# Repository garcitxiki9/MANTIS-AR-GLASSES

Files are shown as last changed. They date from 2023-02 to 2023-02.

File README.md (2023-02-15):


# Mantis AR Glasses
An open source smart glasses



### Features

- Use a bluetooth multimeter and display the obtained data on the screen of the glasses.
- View the temperatures of electronic circuits with the MLX90640 thermal camera.

With these features, the Mantis AR Glasses wearer will be able to use a multimeter from the glasses and monitor circuit temperatures.

> ***This project has been realized by the students of the department of electronics of the institute CIFP Don Bosco LHII.***

- [ Mantis AR Glasses ](#mantis)
- [ Features ](#features)
- [ How did it start? ](#history)
	- [ Reverse engineering ](#reverse)
		- [ Vuzix Blade ](#vuzixblade)
		- [ Mantis Glasses ](#mantisglasses)
- [ What do we need? ](#whatweneed)
	- [ List of materials ](#listofmaterials)
	- [ Circuits and connections ](#circuits)
		- [ ST7735 Display ](#st7735)
		- [ MLX90640 ](#mlx90640)
		- [ Touch sensors ](#touchsensors)
		- [ Power management ](#power)
	- [ Software ](#software)
		- [ Install libraries ](#libraries)
		- [ Select the driver of our display ](#selectdriver)
		- [ Mirrored display ](#mirror)
- [ Bugs and error ](#bugserror)
- [ Thanks and references ](#thanks)
	- [ References ](#references)
- [ Disclaimer ](#disclaimer)

# How did it start?

We had the opportunity to test the Vuzix smart glasses and we thought it would be a good idea to do something similar but open source and cheaper.

One advantage of our glasses is that as they are open source, anyone with sufficient knowledge can improve them or adapt them to their needs.

## Reverse engineering
Before starting to design the parts, program or design the electronic circuits, we had to know how a smart glasses were made inside, so we disassembled the Vuxiz Blade to have a clearer idea of how to realize our project.

### Vuzix Blade

We had a better understanding of the required hardware after disassembling the smart glasses.

### Mantis Glasses




In this photo, you can see the components we used for our glasses based on the Vuzix Blade.

# What do we need?

## List of materials
Here is a detailed list of what we need to build our own smart glasses

- Microcontroller board (e.g. Arduino or ESP32)
- Display module (e.g. OLED or TFT)
- Micro-USB cable for programming and powering the board
- Lithium-ion battery or power bank
- 3D printer to print the frame
- Light reflective material to display the screen
- Power management circuit
- Wi-Fi or Bluetooth module
- Sensors (e.g. accelerometer, gyroscope, proximity)
- Buttons or touchpad for user input
- Wiring and cables to connect the components
- A software development kit and libraries to program the glasses.

In our case, we will use an ESP32 because it already has integrated WiFi and Bluetooth, and our sensor will be a thermal camera and a TFT RGB IPS screen because it offers higher resolution for using the thermal camera.

## Circuits and connections

### ST7735 Display


| ST7735 PIN | ESP32 PIN |
| :--- | :-----:|
| GND | GND |
| VCC | 3V3 | 
| SCL | 15 |
| SDA | 2 | 
| RES | 4 |
| DC | 16 | 
| CS | 17 |
| BLK | No connected |

### MLX90640


| MLX90640 PIN | ESP32 PIN |
| :--- | :-----:|
| GND | GND |
| VIN | 3V3 | 
| SCL | 22 |
| SDA | 21 | 
| PS | GND |

### Touch sensors



| TOUCH PIN | ESP32 PIN |
| :--- | :-----:|
| GND | GND |
| VIN | 3V3 | 
| LEFT | 26 |
| GO BACK | 14 | 
| SELECT | 27 |
| RIGHT | 25 |

### Power management


| BATTERY PIN | ESP32 PIN |
| :--- | :-----:|
| BATT- | GND |
| BAT+ | 3V3 | 
| VOLTAGE DIVIDER OUTPUT  | 34 |

## Software

### Install libraries
To install a library in arduino we have to go to :
- sketch->include library->manage libraries


And a window will open where we can look for the name of the library:
- TFT_eSPI



### Select the driver of our display
Once we have installed the TFT_eSPI library, we need to locate the library folder, which is located in the Arduino folder.
`C:\Users\Carlos\This PC\Documents\Arduino\libraries\TFT_eSPI`
Next, we need to edit the file named
`User_Setup_Select.h`
By default, it will contain the line
`#include <User_Setup.h>`
We need to comment out this line and locate the driver for our screen, in our case
`#include <User_Setups/Setup43_ST7735.h>`
and uncomment it.

It should look something like this:

```c++
...
//#include <User_Setup.h>           // Default setup is root library folder
...
#include <User_Setups/Setup43_ST7735.h>            // Setup file for ESP8266 & ESP32 configured for my ST7735S 80x160
...
```

### Mirrored display


```c++

tft.writecommand(TFT_MADCTL); //access to display memory
tft.writedata(0xE0); // send data to change to mirror effect
```

## Future improvements


- A good improvement of this project would be to implement AI, you can use the Whisper AI to talk and pass the audio to text to send it to ChatGPT and what ChatGPT answers, Whisper passes it to audio.

## Bugs and error

- When you are inside an option (multimeter, battery, info...), if you click left or right, you move through the menu without the need to click back.
- When you are in the thermal camera, if you click back, the program crashes and you need to reset the glasses.
- To connect the multimeter, the glasses must be switched off, first the multimeter is switched on and then the glasses, otherwise they do not connect.
- Check the library and driver for the display. 
- Check that the PS of the thermal camera is connected to GND.

## Thanks and refereces

Thanks to the electronics maintenance teachers for all the help offered during the project.



### References

- 3D case:
	- https://www.youtube.com/watch?v=pdVS8--_uQQ
	
- How to install and use the TFT_eSPI library
	- https://www.youtube.com/watch?v=T2A4cEktt6Q

- Voltage divider design
	- [voltage divider](https://www.pangodream.es/esp32-getting-battery-charging-level) 	

- ST7735 Datasheet
	- [ST7735 Datasheet](https://www.displayfuture.com/Display/datasheet/controller/ST7735.pdf) 	

- c++ image converter
	- [Image converter](http://www.rinkydinkelectronics.com/t_imageconverter565.php) 	

- Bluetooth connection
	- [Bluetooth connection](https://github.com/ludwich66/Bluetooth-DMM)	

## Disclaimer


The glasses are not designed for use in devices or situations where there may be physical injury if the software has errors.

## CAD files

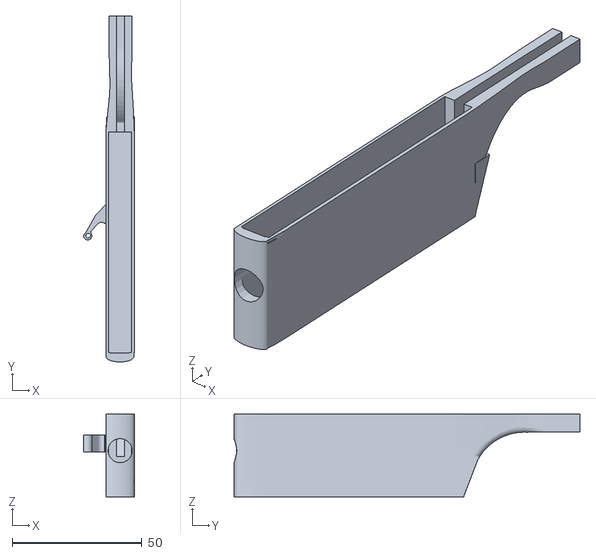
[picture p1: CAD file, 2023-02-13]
3D parts/left.stl
19.7 x 133.4 x 32.0

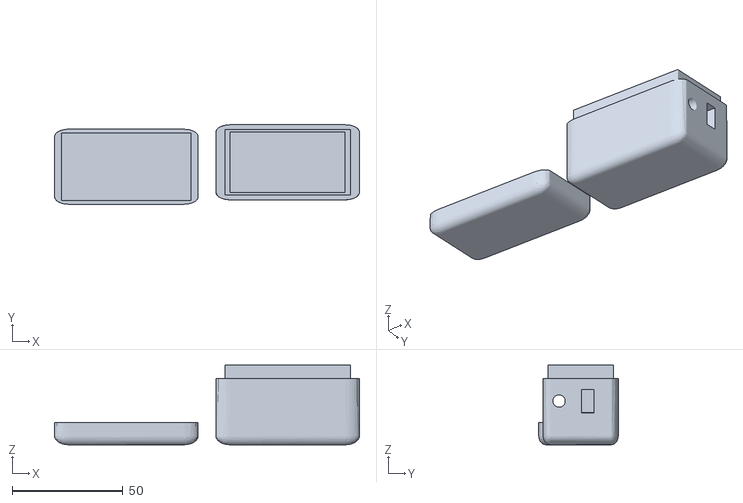
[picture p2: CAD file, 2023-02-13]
3D parts/esp32 and battery case.stl
138.0 x 36.0 x 36.0

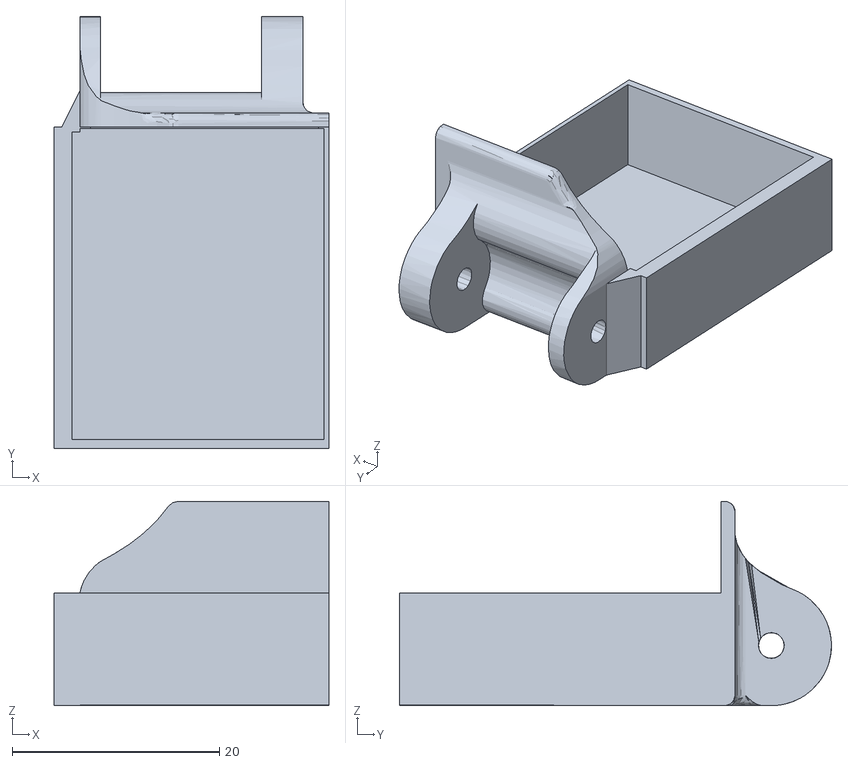
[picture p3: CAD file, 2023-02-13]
3D parts/display case.stl
26.5 x 41.6 x 19.7

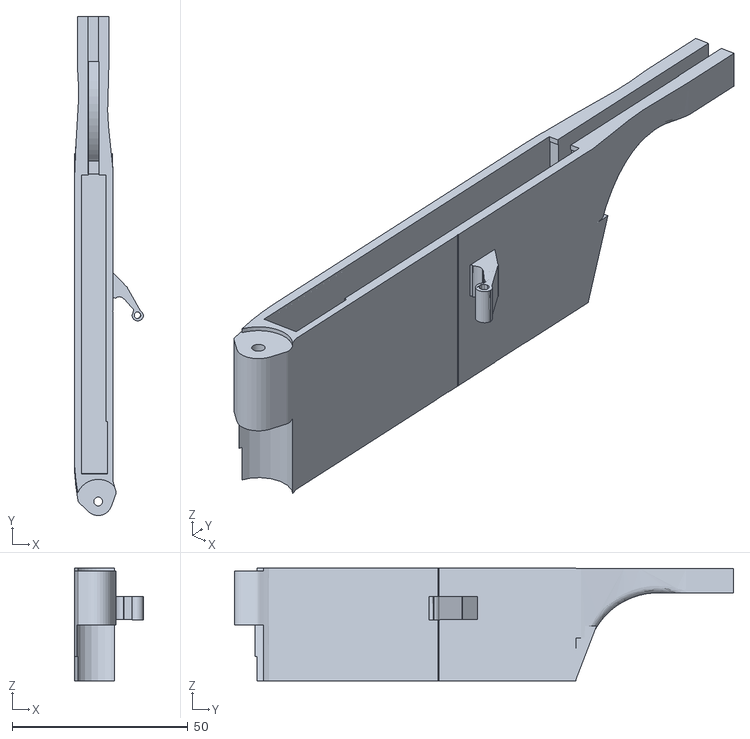
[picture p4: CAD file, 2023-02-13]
3D parts/right.stl
19.7 x 141.8 x 32.0

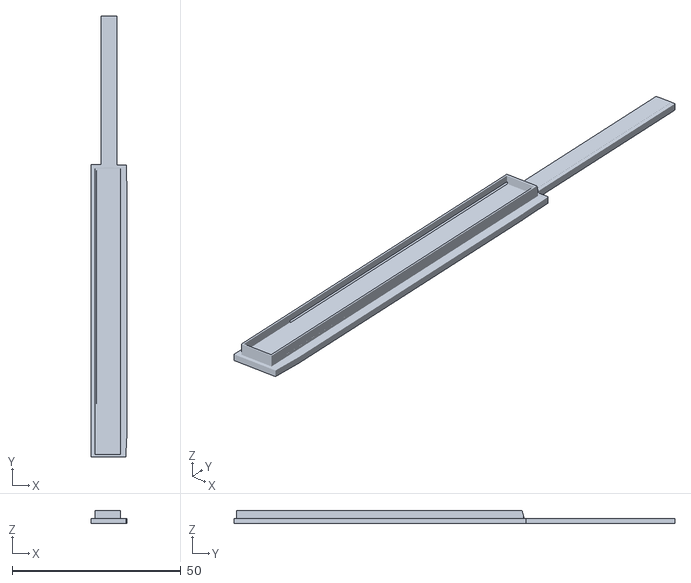
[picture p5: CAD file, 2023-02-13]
3D parts/cover.stl
10.7 x 130.7 x 3.80

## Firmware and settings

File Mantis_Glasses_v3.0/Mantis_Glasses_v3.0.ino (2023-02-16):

#include "variables.h"
#include "ble_multimeter.h"
#include "mlx90640_cam.h"

void setup() {
  //Serial.begin(115200);// only for test
  //Set the data manually without the RTC module
  rtc.setTime(15, 30, 10, 9, 2, 2023); //seconds; minutes; hour; day; month; year  
  
  // Init and get the time
  configTime(gmtOffset_sec, daylightOffset_sec, ntpServer);

  
  display_configuration();
  spr_creation();
  multimeter_inizialization();
  mlx90640_inizialization();
  //declare the buttons as inputs
  pinMode(button_left, INPUT_PULLUP);
  pinMode(button_right, INPUT_PULLUP);
  pinMode(button_select, INPUT_PULLUP);
  pinMode(button_goback, INPUT_PULLUP);
}

void loop() {
  //debugging(); //only for test (this will print the variables states (buttons and menu_states) on serial monitor
  main_page();//all the menu and submenus
  connecting_multimeter();
}

//  ===========================================================================================================
// ||                                         CONFIGURATION OF OUR DISPLAY                                    ||
//  ===========================================================================================================

void display_configuration() {
  tft.init();
  tft.setRotation(3); //landscape = 3
  tft.writecommand(TFT_MADCTL); //access to display memory
  tft.writedata(0xE0); // send data to change to mirror effect
  tft.fillScreen(TFT_BLACK);
  //loading screen
  tft.setSwapBytes(true);
  tft.pushImage(0, 0, 160, 80,  load_page_160x80);
  delay(1250);
  //tft.fillScreen(TFT_BLACK);
}
//  ===========================================================================================================
// ||                                         CREATING SPRITES                                                ||
//  ===========================================================================================================

//By creating sprites, we avoid screen flickering
void spr_creation() {
  spr_background.createSprite(display_width, display_height);
  //spr_mlx90640_background.createSprite(display_width, display_height);
  spr_thermal_camera35x35.createSprite(35, 35);
  spr_multimeter35x35.createSprite(35, 35);
  spr_battery35x35.createSprite(35, 35);
  spr_info35x35.createSprite(35, 35);

  //To correctly display the sprites, we set setSwapBytes to true
  spr_multimeter35x35.setSwapBytes(true);
  spr_thermal_camera35x35.setSwapBytes(true);
  spr_battery35x35.setSwapBytes(true);
  spr_info35x35.setSwapBytes(true);

}

//  ===========================================================================================================
// ||                                  READING BUTTONS TO INCREASE OR DICREASE THE VARIABLE                   ||
//  ===========================================================================================================

void buttons() {
  // read the state of the pushbutton value:
  byte left_state = digitalRead(button_left);
  byte right_state = digitalRead(button_right);

  // check if the pushbutton is pressed. If it is, the button state is HIGH:
  if ((left_state == HIGH) && (right_state == LOW)) {
    p_index = m_index;
    m_index--;
    delay(190);
  }
  if ((right_state == HIGH) && (left_state == LOW)) {
    p_index = m_index;
    m_index++;
    delay(190);
  }
  if( (m_index <= 0)) {
    m_index = 5;
  }
  else if ((m_index > 5)) {
    m_index = 1;
  }
}


//  ===========================================================================================================
// ||                      CALLING THIS WILL SELECT THE ICON AND CHANGE THE SCREEN                            ||
//  ===========================================================================================================

void select_option(int index) {
  // read the state of the pushbutton value:
  byte left_state = digitalRead(button_left);
  byte right_state = digitalRead(button_right);
  byte select_state = digitalRead(button_select);
  byte goback_state = digitalRead(button_goback);

  c_index = index;
  if(p_index != c_index) {
    p_index = c_index;
  }
  //select multimeter
  if(index == 1) {
    x_multimeter = 68;
    x_thermalcamera = 140;
    x_battery = 180;
    x_info = 180;
    str_info = "";
    str_time_hour = "";
    str_time_minutes = "";
    str_time_date = "";
    str_volts = "";
    str_volts_number = "";
    str_option = "Use a blueooth multimeter and check the voltages on the display";
    y_str = 45;
    x_str--;
    if (x_str < -500){
      x_str = 160;
    }
    //if you push select button, the menu_states will change to 1
    if (select_state == HIGH){
      menu_states = 1;
    }
    if (menu_states == 1){
      multimeter_page();
    }
    //if you push goback button, the menu_states will change to 0
    if (goback_state == HIGH){
      menu_states = 0;
    }
    if (menu_states == 0){
      index = 1;
    }

  }
  //select thermal camera
  else if(index == 2) {
    x_multimeter = -10;
    x_thermalcamera = 68;
    x_battery = 140;
    x_info = 180;
    str_info = "";
    str_time_hour = "";
    str_time_minutes = "";
    str_time_date = "";
    str_volts = "";
    str_volts_number = "";
    str_option = "Use the MLX90640 to check temperatures of the circuit";
    y_str = 45;
    x_str--;
    if (x_str < -400){
      x_str = 160;
    }
    //if you push select button, the menu_states will change to 2
    if (select_state == HIGH){
      tft.fillScreen(TFT_BLACK);
      spr_background.deleteSprite();
      menu_states = 2;
    }
    if (menu_states == 2){
      thermalcam_page();
    }
    //if you push goback button, the menu_states will change to 0
    if (goback_state == HIGH){
      menu_states = 0;
    }
    if (menu_states == 0){
      index = 2;
    }
  }
  //select battery icon
  else if(index == 3) {
    x_multimeter = -40;
    x_thermalcamera = -10;
    x_battery = 65;
    x_info = 140;
    y_str = 45;
    str_info = "";
    str_time_hour = "";
    str_time_minutes = "";
    str_time_date = "";
    str_volts = "";
    str_volts_number = "";
    str_option = "Check the battery charge";
    x_str--;
    if (x_str < -200){
      x_str = 160;
    }
    if (select_state == HIGH){
      menu_states = 3;
    }
    if (menu_states == 3){
      battery_page();
    }
    if (goback_state == HIGH){
      menu_states = 0;
    }
    if (menu_states == 0){
      index = 3;
    }
  }
  //info
  else if(index == 4) {
    x_multimeter = -120;
    x_thermalcamera = -120;
    x_battery =  -10;
    x_info =  65;
    y_str = 45;
    str_info = "";
    str_time_hour = "";
    str_time_minutes = "";
    str_time_date = "";
    str_volts = "";
    str_volts_number = "";
    str_option = "Read about this project";
    x_str--;
    if (x_str < -200){
      x_str = 160;
    }
    if (select_state == HIGH){
      menu_states = 4;
    }
    if (menu_states == 4){
      info_page();
    }
    if (goback_state == HIGH){
      menu_states = 0;
    }
    if (menu_states == 0){
      index = 4;
    }
  }
  //menu item not selected
  else if(index == 5) {
    x_multimeter = 145;
    x_thermalcamera = 180;
    x_battery = 180;
    x_info =  180;
    x_str = 30;
    y_str = 60;
    x_str_time_hour = 25;
    y_str_time_hour = 10;
    x_str_time_minutes = 50;
    y_str_time_minutes = 10;
    x_str_time_date = 15;
    y_str_time_date = 35;
    str_volts = "";
    str_volts_number = "";
    str_info = "";
    str_option = "MANTIS GLASSES";
    str_time_hour = rtc.getHour(true);
    str_time_minutes = rtc.getMinute();
    str_time_date = rtc.getDate();
  }

  if(menu_states == 1 || menu_states == 2 || menu_states == 3 || menu_states == 4){
    x_str_time_hour = 800;
    y_str_time_hour = 800;
    x_str_time_minutes = 800;
    y_str_time_minutes = 800;
    x_str_time_date = 800;
    y_str_time_date = 800;
  }
  
  
}

//  ===========================================================================================================
// ||                                   FUNCTION TO DRAW MAIN PAGE                                            ||
//  ===========================================================================================================

void main_page() {

  buttons();
  select_option(m_index);
  spr_background.fillSprite(background_color);
  spr_multimeter35x35.pushImage(0, 0, 35, 35,  multimeter_35x35);
  spr_thermal_camera35x35.pushImage(0, 0, 35, 35,  thermal_camera_35x35);
  spr_battery35x35.pushImage(0, 0, 35, 35,  battery_35x35);
  spr_info35x35.pushImage(0, 0, 35, 35,  info_35x35);

  spr_multimeter35x35.pushToSprite(&spr_background, x_multimeter, 5, TFT_BLACK);
  spr_thermal_camera35x35.pushToSprite(&spr_background, x_thermalcamera, 5, TFT_BLACK);
  spr_battery35x35.pushToSprite(&spr_background, x_battery, 5, TFT_BLACK);
  spr_info35x35.pushToSprite(&spr_background, x_info, 5, TFT_BLACK);
  
  spr_background.drawString(str_option, x_str, y_str, 2);
  spr_background.drawString(str_info, x_str_info, y_str_info, 2);
  spr_background.drawString(str_time_hour, x_str_time_hour, y_str_time_hour, 2);
  spr_background.drawString(str_time_minutes, x_str_time_minutes, y_str_time_minutes, 2);
  spr_background.drawString(str_time_date, x_str_time_date, y_str_time_date, 2);

  spr_background.pushSprite(0, 0);
}

//  ===========================================================================================================
// ||                                   PAGES OF OUR MENU                                                     ||
//  ===========================================================================================================

void multimeter_page() {
  x_multimeter = 600;
  x_thermalcamera = 600;
  x_battery = 600;
  x_info =  600;
  x_str = 20;
  str_option = s_DMM;
}

void thermalcam_page() {
  x_multimeter = 600;
  x_thermalcamera = 600;
  x_battery = 600;
  x_info =  600;
  x_str = 30;
  str_option = "";

  
String myT;
uint16_t mlx90640Frame[834];

    MLX90640_GetFrameData(MLX90640_address, mlx90640Frame);
    float vdd = MLX90640_GetVdd(mlx90640Frame, &mlx90640);
    float Ta = MLX90640_GetTa(mlx90640Frame, &mlx90640);
    float tr = Ta - TA_SHIFT;
    float emissivity = 0.95;
    MLX90640_CalculateTo(mlx90640Frame, &mlx90640, emissivity, tr, mlx90640To);

  for (int i1 = 0 ; i1 < 32 ; i1++) {
   for (int i2 = 0 ; i2 < 24 ; i2++)  {
    float tT = mlx90640To[i1+i2*32];
    float mycolor;
    
    //get Iron Palette 
    mycolor = 0;//Black
    mycolor = (tT>=30?RGB565(0x20, 0x00, 0x8C):mycolor);//Blue
    mycolor = (tT>=80?RGB565(0xCC, 0x00, 0x77):mycolor);//Purple
    mycolor = (tT>=130?RGB565(0xFF, 0xD7, 0x00):mycolor);//Gold
    mycolor = (tT>=180?RGB565(0xFF, 0xFF, 0xFF):mycolor);//White

    tft.fillRect(1+i1*3, tft.height()-i2*3, 3,3, mycolor);
    if (i1+i2*32==768/2+15) {myT=String(tT,0); tft.fillRect(1+i1*3, tft.height()-i2*3, 3,3, RGB565(0x00, 0x00, 0xff));} //Center
  }
 }

  tft.fillRect(100,1, 60,60, TFT_WHITE);
  tft.setTextSize(2);
  tft.setTextColor(TFT_BLACK);
  tft.setCursor(100, 30);
  tft.print(myT+"C");
  
}

void battery_page() {
  x_multimeter = 600;
  x_thermalcamera = 600;
  x_battery = 600;
  x_info =  600;
  y_str_info = 600;
  x_str = 600;
  x_str_volts = 5;
  y_str_volts = 30;
  x_str_volts_level = 5;
  y_str_volts_level = 15;
  if (battery_volts >= battery_level[2]){
    str_volts = "High charge level";
    str_volts_number = battery_volts;
    
    }
  else if (battery_volts < battery_level[2] && battery_volts > battery_level[1]){
    str_volts = "Medium charge level";
    str_volts_number = battery_volts;
    }
  else if (battery_volts < battery_level[1] && battery_volts > battery_level[0]){
    str_volts = "Low charge level";
    str_volts_number = battery_volts;
    }
  
}
void info_page() {
  x_multimeter = 600;
  x_thermalcamera = 600;
  x_battery = 600;
  x_info =  600;
  y_str_info = 10;
  str_option = "";
  str_info = "This project has been made by the students of the Electronics Department of Don Bosco";
  x_str_info--;
  if (x_str_info < -630){
    x_str_info = 160;
  }
}


//  ===========================================================================================================
// ||                              PRINT INFORMATION OF THE VARIABLES IN SERIAL MONITOR                       ||
//  ===========================================================================================================

void debugging() {
  /*
  byte left_state = digitalRead(left);
  byte right_state = digitalRead(right);
  byte select_state = digitalRead(select);
  byte goback_state = digitalRead(goback);
  Serial.println("");
  Serial.println("left\tright\tselect\tgoback\tm_index\tp_index\tc_index\tmenu_states");
  Serial.print(left_state);  Serial.print("\t");  Serial.print(right_state);  Serial.print("\t");  Serial.print(select_state); Serial.print("\t");  Serial.print(goback_state); Serial.print("\t");  Serial.print(m_index); Serial.print("\t");  Serial.print(p_index);  Serial.print("\t");  Serial.print(c_index); Serial.print("\t");  Serial.print(menu_states);
  delay(100);
  */
}

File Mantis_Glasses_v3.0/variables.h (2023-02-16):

//  ===========================================================================================================
// ||                                            LIBRARIES AND ICONS                                          ||
//  ===========================================================================================================

#include <TFT_eSPI.h> // Graphics and font library for ST7735 driver chip
#include <SPI.h>
#include <Wire.h>
#include "MLX90640_API.h" //github.com/sparkfun/SparkFun_MLX90640_Arduino_Example
#include "MLX90640_I2C_Driver.h"
#include <EEPROM.h>
#include <ESP32Time.h>
#include <BLEDevice.h>
#include <Pangodream_18650_CL.h>
#include "load_screen_160x80.h"
#include "multimeter35x35.h"
#include "thermal_camera35x35.h"
#include "battery35x35.h"
#include "info35x35.h"


//  ===========================================================================================================
// ||                                            SIZE OF OUR DISPLAY                                          ||
//  ===========================================================================================================

#define display_width  160
#define display_height 80
//  ===========================================================================================================
// ||MISO = 2                                                                                                 ||
// ||SCLK = 15                                                                                                ||
// ||CS = 17                                                                                                  ||
// ||DC = 16                                                                                                  ||
// ||RST = 4                                                                                                  ||
//  ===========================================================================================================

//  ===========================================================================================================
// ||                              SPRITES                                                                    ||
//  ===========================================================================================================
TFT_eSPI tft = TFT_eSPI();  // Invoke library, pins defined in User_Setup.h
TFT_eSprite spr_multimeter35x35 = TFT_eSprite(&tft);  
TFT_eSprite spr_thermal_camera35x35 = TFT_eSprite(&tft); 
TFT_eSprite spr_battery35x35 = TFT_eSprite(&tft);
TFT_eSprite spr_info35x35 = TFT_eSprite(&tft);
TFT_eSprite spr_background = TFT_eSprite(&tft); 
 


//  ===========================================================================================================
// ||                              BUTTON COUNTER VARIABLES                                                   ||
//  ===========================================================================================================
byte m_index = 5; // menu index
byte p_index = 5; // previous page
byte c_index = 5; // current page

//  ===========================================================================================================
// ||                             BUTTONS GPIO                                                                ||
//  ===========================================================================================================
const byte button_left = 26;
const byte button_right = 25;
const byte button_select = 27;
const byte button_goback = 14;
//  ===========================================================================================================
// ||                              MENU STATES                                                                ||
//  ===========================================================================================================
byte menu_states = 0; //main menu
//  ===========================================================================================================
// ||menu_states = 0 -> main menu                                                                             ||
// || menu_states = 1 -> multimeter                                                                           ||
// || menu_states = 2 -> thermal camera                                                                       ||
// ||menu_states = 3 -> battery info                                                                          ||
// ||menu_states = 4 -> info                                                                                  ||
//  ===========================================================================================================

//  ===========================================================================================================
// ||                             BATTERY LEVEL                                                               ||
//  ===========================================================================================================
Pangodream_18650_CL BL;
float battery_volts = BL.getBatteryVolts();
float battery_level[] = {2.3, 3.0, 3.6};
//ADC 34 pin for read the volts

//  ===========================================================================================================
// ||                     VARIABLES TO CONTROL THE MOVEMENT AND POSITIONING OF SPRITES AND STRINGS            ||
//  ===========================================================================================================
int x_multimeter = 68;
int x_thermalcamera = 140;
int x_battery = 200;
int x_info = 260;

int x_str = 45;
int y_str = 45;

int x_str_info = 0;
int y_str_info = 0;

int x_str_volts = 0;
int y_str_volts = 0;

int x_str_volts_level = 0;
int y_str_volts_level = 0;

int x_str_time_hour = 0;
int y_str_time_hour = 0;

int x_str_time_minutes = 0;
int y_str_time_minutes = 0;

int x_str_time_date = 0;
int y_str_time_date = 0;

int background_color = TFT_BLACK;


//  ===========================================================================================================
// ||                              VARIABLES TO CHANGE THE DISPLAYED INFORMATION                              ||
//  ===========================================================================================================
String str_option = "";
String str_info = "";
String str_volts_number = "";
String str_volts = "";
String str_time_hour = "";
String str_time_minutes = "";
String str_time_date = "";
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

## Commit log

2023-02-13 Add files via upload
    These are the 3D designs for mounting the glasses
    [cover.stl, display case.stl, esp32 and battery case.stl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]
2023-02-14 Add files via upload
    These are the circuit diagrams for the buttons and the voltage divider.
